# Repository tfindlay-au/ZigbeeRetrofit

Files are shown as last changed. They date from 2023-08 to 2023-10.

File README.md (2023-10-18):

# Zigbee Retrofit

### Purpose
This project provide a PCB that will retrofit into an M5Stack Zigbee Unit but replaces the CC2630 with the more common and better supported CC2531 chipset.

Designed in KiCad 6.0.9
The output board measures 50mm x 20mm and contains cutouts for mounting in the case /w lego fittings

The design incorporates a Tag-Connect 10 pad pogo pin (TC-2050-NL) footprint to write/flash firmware.
The design also incorporates a 4-pin Grove connector with UART interface for easy connection with M5Stack Atom products.

The design also uses the following symbols:
- 110990037: Seed Studio Grove connector
- CC2531F256RHAT: TI Chip Zigbee chip
- TC2050-IDC-NL: 10 pin flash connection
- U.FL-R-SMT-1_10: UFL antenna connector
- ECS-320-13-42-CKM-TR: 32 Mhz Crystal
- ECS-.327-12.5-34RR-TR: 32.768 kHz Crystal

### Next Steps
- Add USB port ?
- Add an RF shield to go over the chip

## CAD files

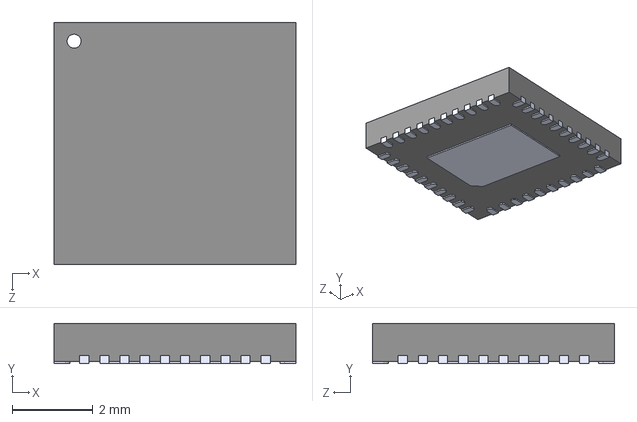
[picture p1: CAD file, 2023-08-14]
CC2531F256RHAT/CC2531F256RHAT.step
6.00 x 1.00 x 6.00 mm

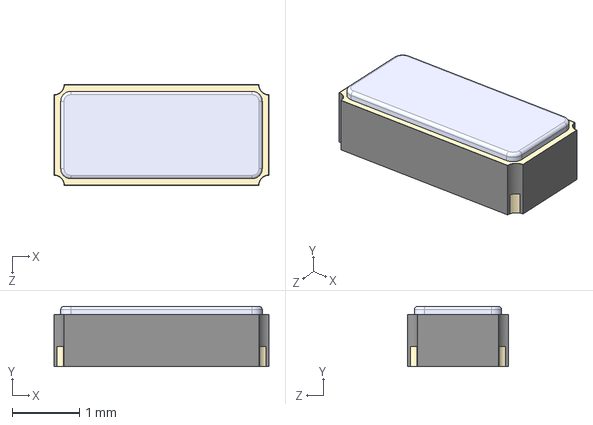
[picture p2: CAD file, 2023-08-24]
ECS-.327-12.5-34RR-TR/ECS-.327-12.5-34RR-TR.step
3.20 x 0.9 x 1.50 mm

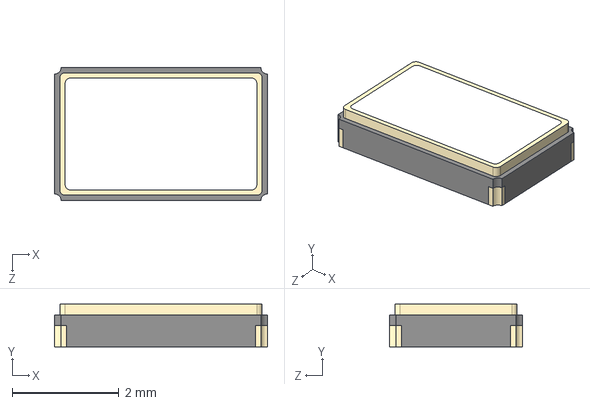
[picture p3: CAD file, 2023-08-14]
ECS-320-13-42-CKM-TR/ECS-320-13-42-CKM-TR.step
4.00 x 0.8 x 2.50 mm

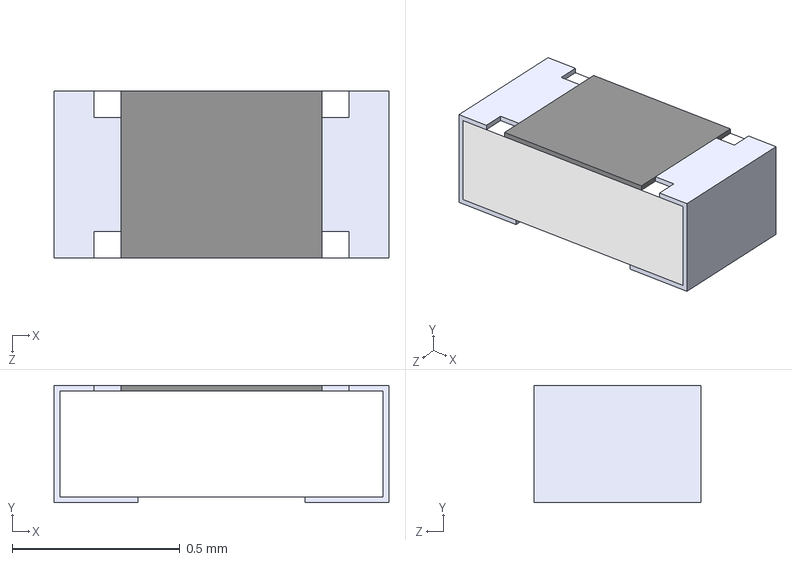
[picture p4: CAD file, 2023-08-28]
ERJ-2GEJ151X/ERJ-2GEJ151X.step
1 x 0.35 x 0.5 mm

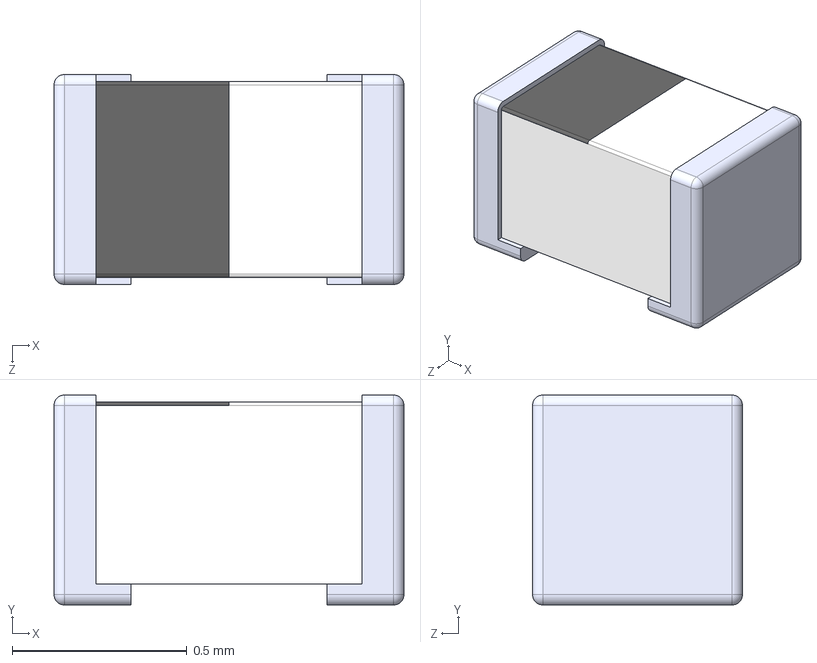
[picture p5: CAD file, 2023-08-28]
MHQ1005P2N0ST000/MHQ1005P2N0ST000.step
1.00 x 0.6 x 0.6 mm

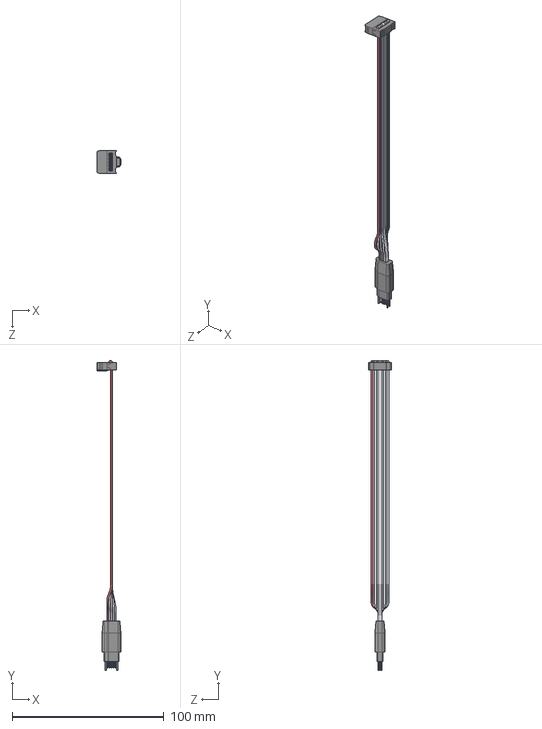
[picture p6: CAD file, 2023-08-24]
TC2050-IDC-NL/TC2050-IDC-NL.step
15.7 x 204.4 x 15.2 mm

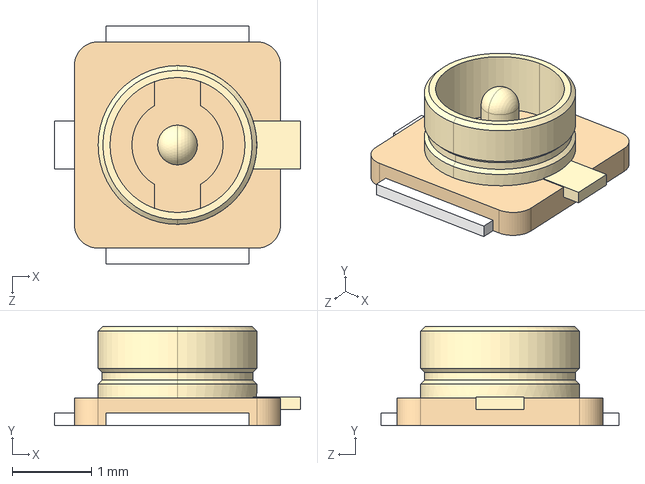
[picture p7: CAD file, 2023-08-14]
U.FL-R-SMT-1_10/U.FL-R-SMT-1_10_.step
3.10 x 1.25 x 3.00 mm

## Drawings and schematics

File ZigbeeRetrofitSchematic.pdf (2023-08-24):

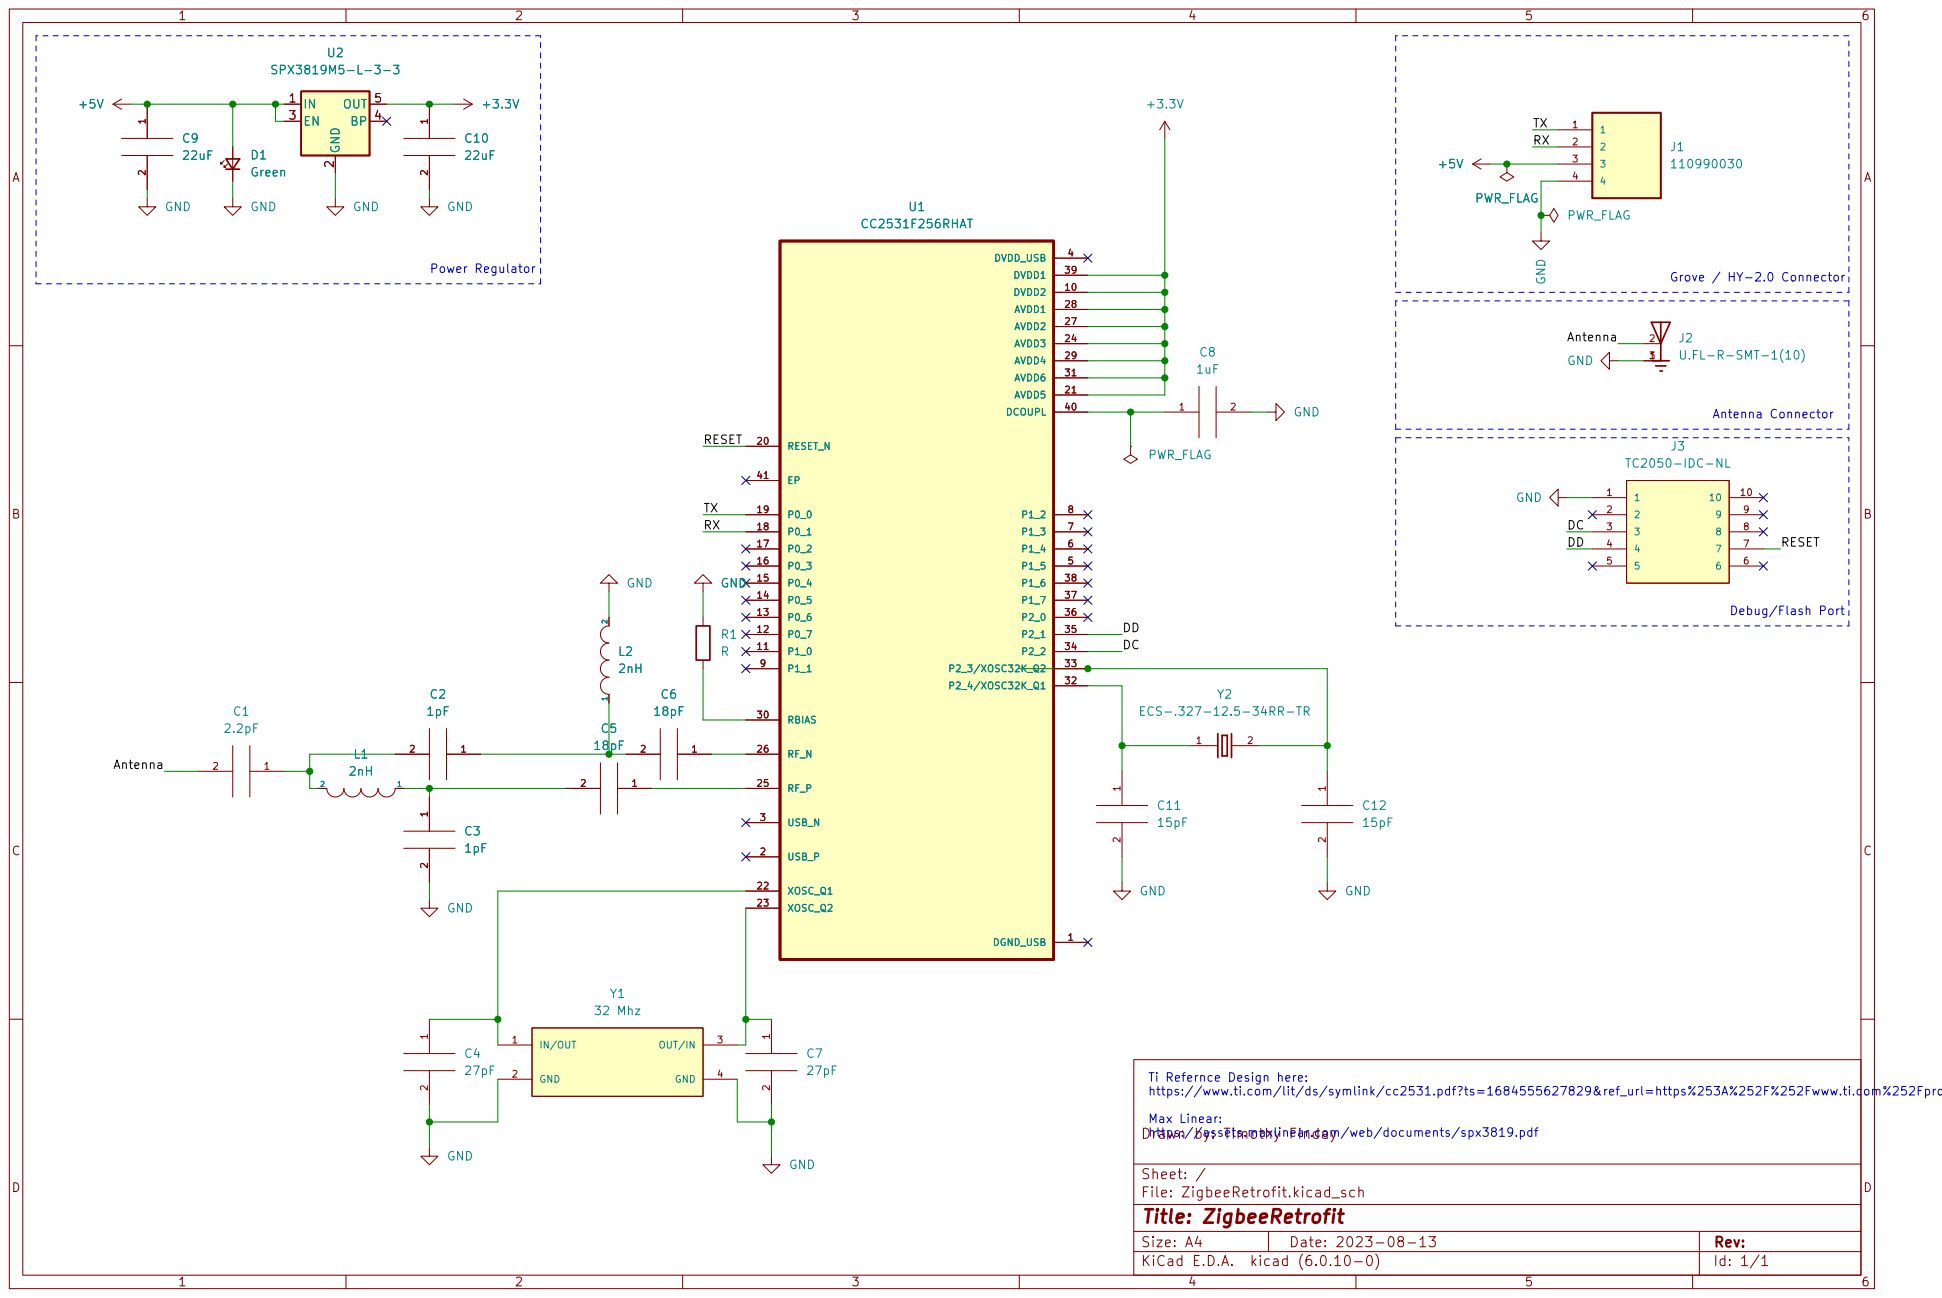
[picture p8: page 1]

2 EN 3 BP 4 OUT 5 U2 SPX3819M5-L-3-3 D1Green GND GND

Ti Refernce Design here:
https://www.ti.com/lit/ds/symlink/cc2531.pdf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 Max Linear: https://assets.maxlinear.com/web/documents/spx3819.pdf

File: ZigbeeRetrofit.kicad_sch Sheet: / Drawn by: Timothy Finday

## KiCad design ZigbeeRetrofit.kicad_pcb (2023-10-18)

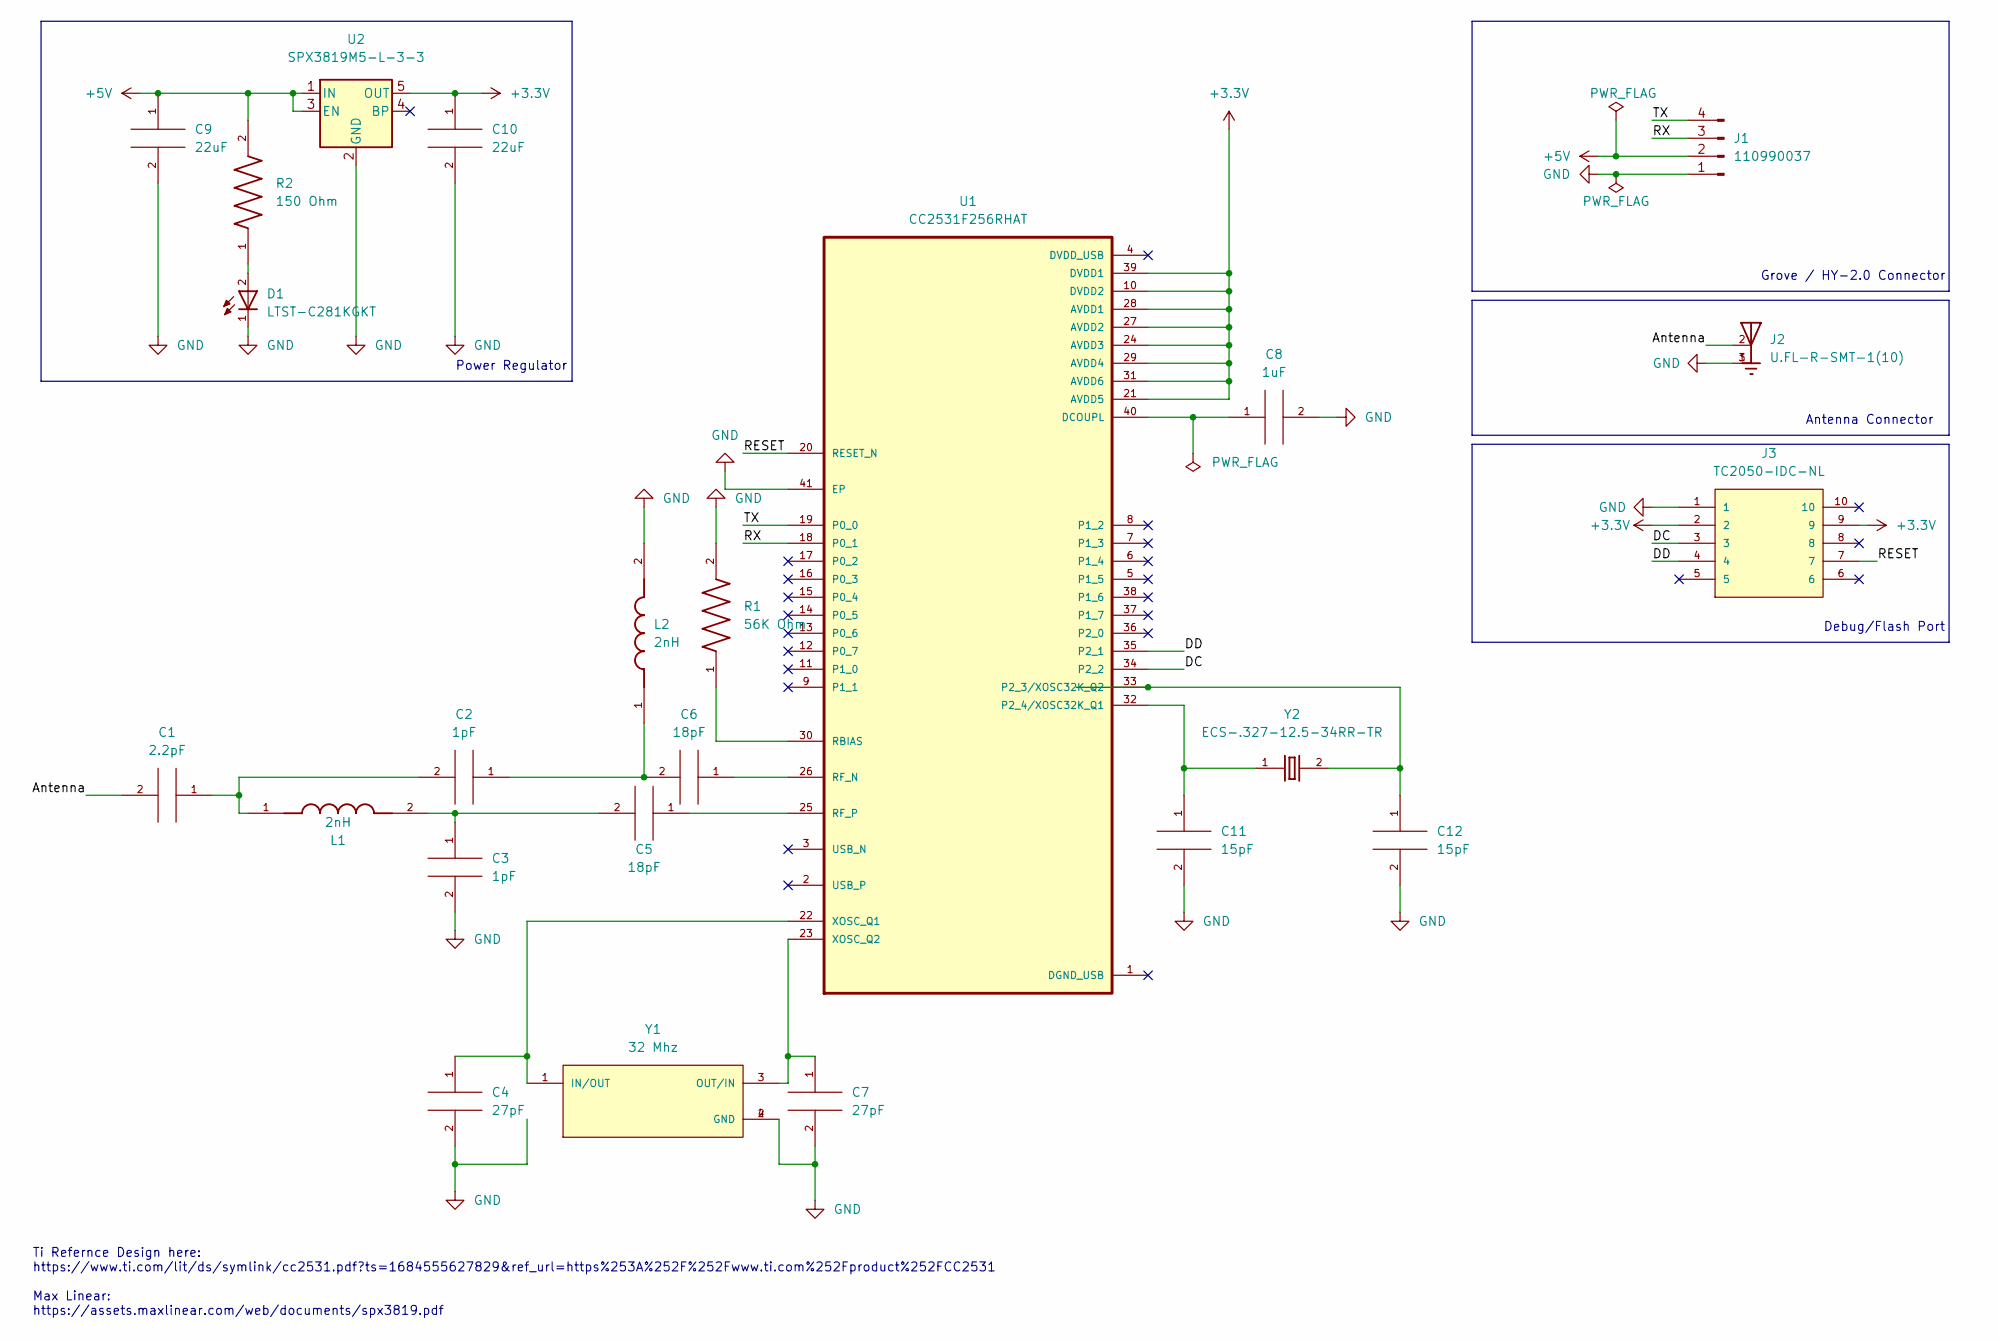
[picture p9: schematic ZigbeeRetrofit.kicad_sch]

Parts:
C1: 2.2pF; C_0402_1005Metric
C2, C3: 1pF; C_0402_1005Metric
C4, C7: 27pF; C_0402_1005Metric
C5, C6: 18pF; C_0402_1005Metric
C8: 1uF; C_0402_1005Metric
C9, C10: 22uF; C_0402_1005Metric
C11, C12: 15pF; C_0402_1005Metric
D1: LTST-C281KGKT; 0402(POL)
J1: 110990037; JST_PH_S4B-PH-K_1x04_P2.00mm_Horizontal; PARTREV A
J2: U.FL-R-SMT-1(10); HRS_U.FL-R-SMT-1(10)
J3: TC2050-IDC-NL; TAG-CONNECT_TC2050-IDC-NL; PARTREV A
L1, L2: 2nH; INDC1006X60N
R1: 56K Ohm; RES_ERJ-2GEJ563X; PARTREV 3/1/2020
R2: 150 Ohm; RES_ERJ-2GEJ151X; PARTREV 3/1/2020
U1: CC2531F256RHAT; QFN50P600X600X100-41N
U2: SPX3819M5-L-3-3; SOT-23-5
Y1: 32 Mhz; XTAL_ECS-320-13-42-CKM-TR; PARTREV 11/11
Y2: ECS-.327-12.5-34RR-TR; XTAL_ECS-.327-12.5-34RR-TR

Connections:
+3.3V: C10.1, J3.2, J3.9, U1.10 (DVDD2), U1.21 (AVDD5), U1.24 (AVDD3), U1.27 (AVDD2), U1.28 (AVDD1), U1.29 (AVDD4), U1.31 (AVDD6), U1.39 (DVDD1), U2.5 (OUT)
+5V: C9.1, J1.2, R2.2, U2.1 (IN), U2.3 (EN)
/Antenna: C1.2, J2.2
/DC: J3.3, U1.34 (P2_2)
/DD: J3.4, U1.35 (P2_1)
/RESET: J3.7, U1.20 (RESET_N)
/RX: J1.3, U1.18 (P0_1)
/TX: J1.4, U1.19 (P0_0)
GND: C3.2, C4.2, C7.2, C8.2, C9.2, C10.2, C11.2, C12.2, D1.1, J1.1, J2.1, J2.3, J3.1, L2.2, R1.2, U1.41 (EP), U2.2 (GND), Y1.2 (GND), Y1.4 (GND)
unnamed: C1.1, C2.2, L1.1
unnamed: C2.1, C6.2, L2.1
unnamed: C3.1, C5.2, L1.2
unnamed: C4.1, U1.22 (XOSC_Q1), Y1.1 (IN/OUT)
unnamed: C5.1, U1.25 (RF_P)
unnamed: C6.1, U1.26 (RF_N)
unnamed: C7.1, U1.23 (XOSC_Q2), Y1.3 (OUT/IN)
unnamed: C8.1, U1.40 (DCOUPL)
unnamed: C11.1, U1.32 (P2_4/XOSC32K_Q1), Y2.1
unnamed: C12.1, U1.33 (P2_3/XOSC32K_Q2), Y2.2
unnamed: D1.2, R2.1
unnamed: R1.1, U1.30 (RBIAS)

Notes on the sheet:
Antenna Connector
Grove / HY-2.0 Connector
Debug/Flash Port
Ti Refernce Design here: https://www.ti.com/lit/ds/symlink/cc2531.pdf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 Max Linear: https://assets.maxlinear.com/web/documents/spx3819.pdf
Power Regulator

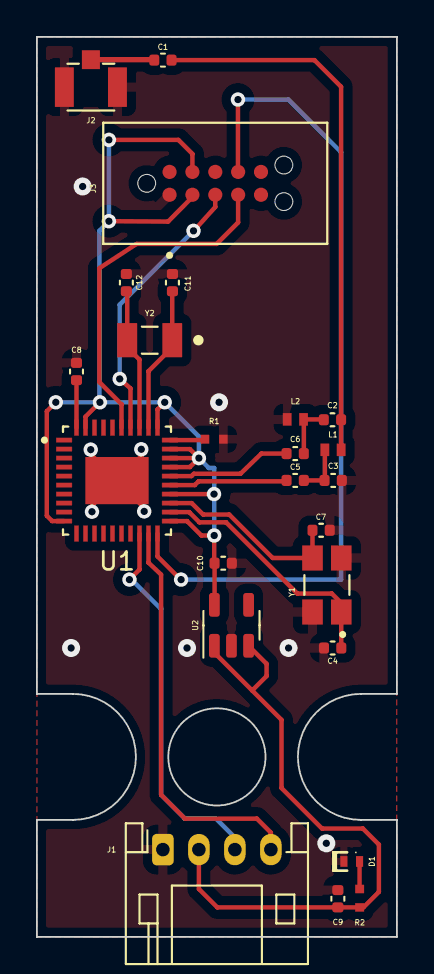
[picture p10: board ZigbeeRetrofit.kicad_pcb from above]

Board: 2 copper layers, 20.0 x 50.0 mm, 24 parts (0 on the bottom side), 21 nets.

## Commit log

2023-08-14 Adding current schematic
2023-08-24 Updated crystals
    [ECS-.327-12.5-34RR-TR.step, TC2050-IDC-NL.step, ZigbeeRetrofit.kicad_sch]
2023-08-27 Updated Symbols to clear ERC
    [ZigbeeRetrofit.kicad_sch]
2023-08-28 Drafted first component layout for PCB
    [ZigbeeRetrofit.kicad_pcb]
2023-08-28 Updated layout with 3d models
    [ERJ-2GEJ151X.step, ERJ-2GEJ563X.step, MHQ1005P2N0ST000.step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]
2023-09-03 Added ground
    [ZigbeeRetrofit.kicad_pcb, ZigbeeRetrofit.kicad_sch]
2023-09-04 Updated grove connector
    [ZigbeeRetrofit.kicad_pcb, ZigbeeRetrofit.kicad_sch]
2023-10-15 Revision 0.2 - Draft
    [ZigbeeRetrofit.kicad_pcb, ZigbeeRetrofit.kicad_sch]
2023-10-18 Revision 0.2 - Final
    [ZigbeeRetrofit.kicad_pcb, ZigbeeRetrofit.kicad_sch]
